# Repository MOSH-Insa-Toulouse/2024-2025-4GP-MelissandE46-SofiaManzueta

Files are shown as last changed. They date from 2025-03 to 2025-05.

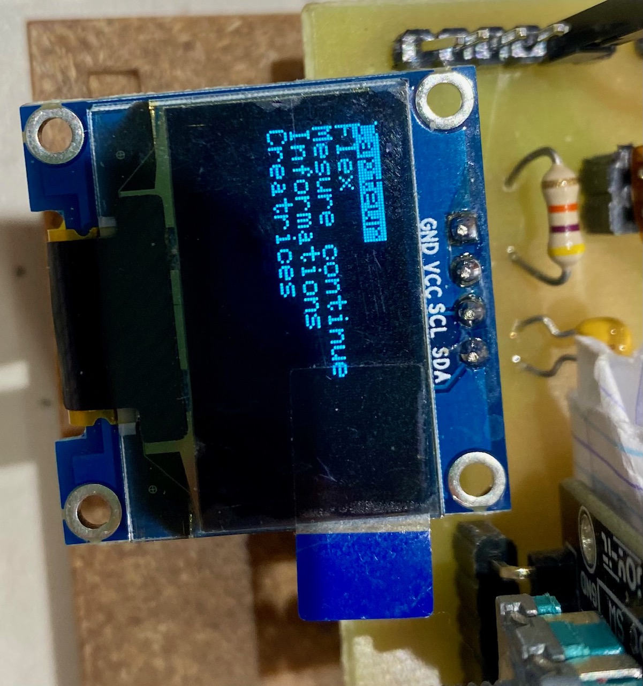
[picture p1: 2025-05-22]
Code Arduino/Menu.jpg

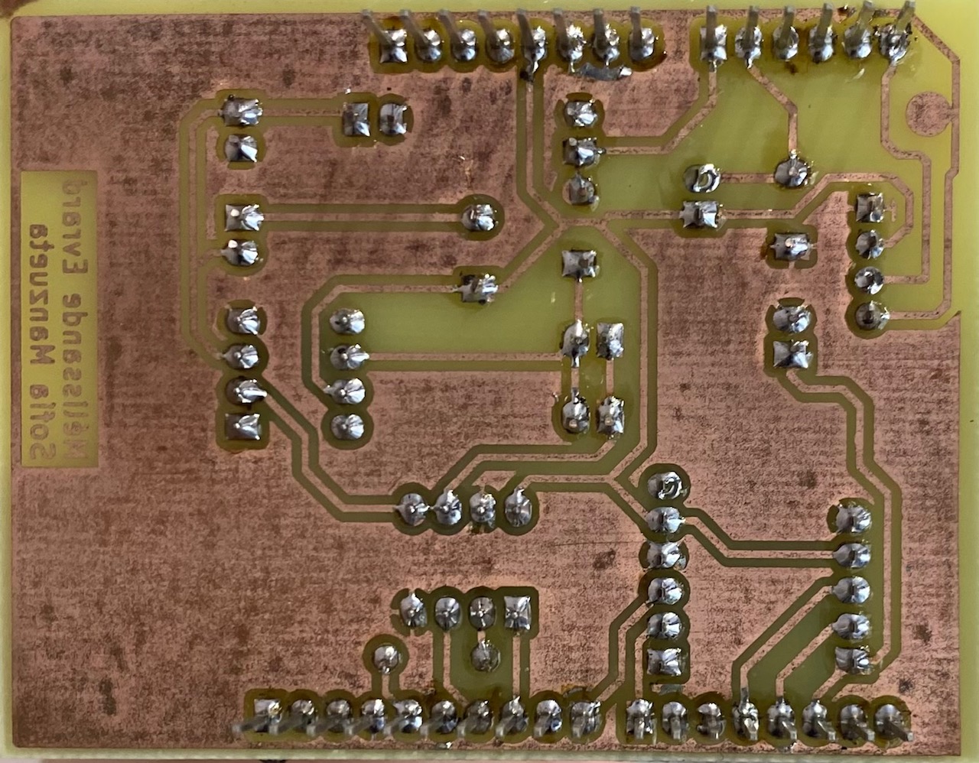
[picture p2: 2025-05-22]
Kidad - Projet capteur/PCB après perçage et soudage.jpg

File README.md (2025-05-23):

# 2024-2025-4GP-MelissandE46-SofiaManzueta

# Projet Capteur

## Sommaire 
*  [Objectifs de ce projet](#objectifs-de-ce-projet)
*  [Déroulé du projet](#diagramme-du-projet)
*  [Simulation du capteur graphite sur LTSpice](#simulation-du-capteur-graphite-sur-ltspice)
*  [Shield PCB sur Kicad](#shield-pcb-sur-kicad)
*  [Code Arduino](#code-arduino)
*  [App Android](#app-android)
*  [La Datasheet](#la-datasheet)

## Objectifs de ce projet

<details>
<summary>  Création d'un capteur de contrainte en graphite  </summary>
   Nous allons utiliser les traces de crayon sur du papier comme une jauge de contrainte pour détecter les déformations en compression et en traction.<br/>
   Les mines de crayon standard sont composées de fines particules de graphite liées entre elles par des liants argileux. Lorsqu'on utilise un crayon, le frottement entre la mine et le papier entraîne le frottement de particules de graphite qui adhèrent aux fibres du papier. Ces traces de crayon peuvent être considérées comme de minces films conducteurs constitués de réseau de particules de graphite percolées sur le papier qui peuvent prendre des formes et des motifs arbitraires. L'expansion et la contraction de ce réseau de particules de graphite, induites par des contraintes mécaniques ou des interactions chimiques, devraient grandement affecter la qualité des contacts interparticulaires et donc le conductivité électrique globale. Il est important de noter que les mines de crayon plus dures contiennent une proportion plus élevée de liants argileux, alors que les mines plus molles contiennent une proportion plus grande de particules de graphite. Ces dernières permettent d'obtenir une résistance de base plus faible qu'avec les mines plus dures. Il a été observé que les variations de résistance moyennes étaient linéairement liées aux amplitudes moyennes de déflexion, avec des écarts d'environ 1%.<br/>
En utilisant la théorie de la percolation, la conductance totale G_{tot} d'un réseau de conducteurs hautement désordonné est :<br/>
   $$G_{tot}=G_0e^{-\xi_c}$$, ici $$\xi_c$$ est la valeur de $$\xi$$ au seuil de percolation qui est le point où un cluster connecté infiniment grand commence à émerger lorsque des paires de nanoparticules voisines choisie au hasard sont connectées par des conducteurs dans un ordre décroissant de valeurs de G<br/>
   If $$-\delta\lambda/2\leq\delta\lambda/2$$,<br/>
   $$\xi_c= \left( {\frac{2f_c\delta\lambda\delta\epsilon}{1-f_v}} \right)^{1/2}+\delta_M-\delta\lambda/2+\epsilon_M-\delta\epsilon/2$$ <br/>
   If $$\delta\lambda/2-\delta\epsilon/2\leq\delta\epsilon/2-\delta\lambda/2$$, <br/>
   $$\xi_c=\lambda_M+\epsilon_M-\left( \frac{1}{2}-\frac{f_c}{1-f_v} \right)\delta\epsilon$$<br/>
   *  $$f_c$$ est la fraction des conducteurs<br/>
   *  $$f_v$$ est la fraction de vide<br/>
   *  $$\lambda_M=L_M\beta$$ et $$E_M=E_{CM}/kT$$ sont les valeurs moyennes des distributions, avec $$L_M$$ l'espace moyen (hors vide) séparant les nanoparticules voisines et $$E_{CM}$$ l'énergie coulombienne de charge moyenne<br/>
   *  $$\delta\lambda$$ et $$\delta\epsilon$$ sont les largeurs des distributions
  
</details>

<details>
<summary>  Réalisation d'un shield PCB pour Arduino UNO  </summary>
   Nous avons créer un shield PCB afin de relier à l'arduino UNO :<br/>  
        *  Un écran OLED  <br/>
        *  Un potentiomètre digital en SPI   <br/>
        *  Un amplificateur transimpédance, lui-même relié au capteur graphite décrit plus haut et au potentiomètre digital  <br/>
        *  Un module Bluetooth  <br/>
        *  Un flex sensor  <br/>
        *  Un encodeur rotatoir auquel on ajoute un déparasite (une capacité entre la clock et le ground)   <br/><br/>

</details>

<details>
<summary>  Création d'un code Arduino  </summary>
Le code crée à l'occasion de ce projet permet de se déplacer dans un menu à l'aide de l'encodeur rotatoire et accéder à différentes fonctions telles que :<br/>
   -La fonction Capteur qui mesure la résistance du capteur graphite, l'affiche sur l'écran OLED et la transmet par bluetooth<br/>
   -La fonction Flex qui mesure la résistance du flex sensor et l'affiche sur l'écran OLED<br/>
   -La fonction Mesure continue qui indique à l'utilisateur la marche à suivre pour réaliser une mesure en continue, que ce soit pour le flex sensor ou le capteur graphite * <br/>
   -La fonction Informations qui renvoie l'utilisateur vers l'application pour Android pour obtenir plus d'informations, l'écran OLED étant très limité<br/>
   -La fonction Creatrices qui indique tout simplement par qui a été réalisé ce projet<br/>

   *Un fil reliant la pin Switch de l'encodeur rotatoire avec le flex sensor a été ajouté. Le but principal est d'agir comme une résistance pull-up pour pouvoir utiliser le bouton switch plus simplement. Cependant, il permet également d'utiliser le flex sensor comme un bouton. En maintenant le flex sensor en compression, on obtient donc des mesures en continue.
   
</details>

<details>
<summary>  Élaboration d'une app Android  </summary>
  Une application a été créée à l'aide de MIT App Inventor (https://appinventor.mit.edu/). Celle-ci permet d'accéder aux mesures réalisées par le capteur graphite, de les afficher dans un graphe et de récupérer ses valeurs dans un fichier. Elle permet également d'obtenir de plus amples informations sur le contexte de ce projet lorsqu'on arrive sur l'écran Informations. Les photos de la partie Designers (ce qui est vu par l'utilisateur) et la partie Blocks (le code derrière l'application) sont disponibles dans le dossier Application Android.
</details>

<details>
<summary>  Rédaction datasheet  </summary>
  Les données de la datasheet proviennent des mesures réalisées avec le code Arduino sur le circuit présenté précédemment. Pour les mines 6B à HB, nous avons mesurer la résistance du capteur graphite pour différentes déformations en tension et en compression. Pour ces déformations, nous avons utilisé des cylindres avec des diamètres de 2cm, 2.5cm, 3cm, 3.5cm, 4cm, 4.5cm et 5cm. Cela nous donne donc des déformations respectivement de 0.1, 0.08, 0.067, 0.057, 0.05, 0.044, 0.04 puisque nous avons mesuré l'épaisseur du capteur e = 0.2cm et que $$\epsilon = \frac{e}{D}$$. On obtient ainsi les courbes caractéristiques suivantes. 
   



Comme on s'y attendait, en cas de compression, la résistance du capteur graphite diminue lorsque la déformation $$\epsilon$$ augmente. A l'inverse, en cas de tension, la résistance du capteur graphite augmente en fonction de la déformation $$\epsilon$$. Pour ces deux cas de figure, nous pouvons observer que la pente de la courbe est dépendante de la mine utilisée. En effet, la variation relative de résistance est plus élevée pour les mines plus dures, comme cela est décrit dans l'article Pencil Drawn Strain Gauges and Chemiresistors on Paper de Cheng-Wei Lin, Zhibo Zhao, Jaemyung Kim et Jiaxing Huang.


Les résultats du capteur graphite peuvent également être comparés à ceux obtenus avec un flex sensor commercial (celui-ci ne peut être utilisé qu'en tension). Tout d'abord, on peut remarquer que les mesures du flex sensor sont bien plus régulières que celles du capteur graphite. De plus, ses variations relatives de résistance sont plus élevées. Il est important de noter que les mesures du capteur graphite, que ce soit en tension ou en compression, sont peu fiables et dépendent en grande partie du reste du matériel utilisé. En effet, d'une mesure à une autre dans des conditions similaires les résultats du capteur peuvent grandement varier. De plus, pour obtenir des résultats cohérents, nous avons dû emprunter les pinces crocodiles d'un autre groupe, sinon peu importe la déformation et la mine utilisées la résistance mesurée était infinie.<br/><br/>
Nous pouvons donc en conclure que le capteur présenté à l'avantage d'être simple, sobre et abordable. Cependant, ses performances sont encore très éloignées de celles d'un flex sensor commercial. De plus, nous avons remarqué que nous devions régulièrement remettre du graphite sur le capteur et le remplacer par un nouveau après l'avoir utilisé en compression et en tension. Cela va donc à l'encontre du principe de la low-tech.

</details>

## Déroulé du projet 

<details>
<summary>  Etapes du projet :  </summary>
  
  - [x] Attribution des inputs de l'arduino aux différents composants
  - [X] Electronique Analogique
  - [x] Schématique et routage KiCad  
  - [x] Impression du circuit
  - [x] Percage
  - [x] Montage du circuit
  - [x] Code Arduino
  - [x] App Android
  - [x] Création du banc de test
  - [x] Création de la datasheet
</details>

## Simulation du capteur graphite sur LTSpice 
* Création d'un capteur de contrainte en graphite
<br/>
Sur le schéma ci-dessus, la partie supérieure à gauche sert à modéliser le capteur graphite.<br/>
C2 filtre le bruit d'alimentation.<br/>
C3 et R5 sont un filtre de sortie.<br/>
C4 et R4 sont un filtre actif.<br/>
R3 correspond au potentiomètre, il permettra donc un changement de calibre.<br/>
C1 et R2 sont un filtre pour le bruit en courant.<br/>
R1 et C1 sont un filtre pour les bruits en tension.<br/>
V3 et C5 simule du bruit.<br/>

## Shield PCB sur Kicad

Des images du schematic, modèle 3D et PCB finale entre autres sont disponibles [ici](https://github.com/MOSH-Insa-Toulouse/2024-2025-4GP-MelissandE46-SofiaManzueta/tree/main/Kidad%20-%20Projet%20capteur)

## Code Arduino

Le code se trouve ici avec une photo du menu déroulant : [Code Arduino](https://github.com/MOSH-Insa-Toulouse/2024-2025-4GP-MelissandE46-SofiaManzueta/tree/main/Code%20Arduino/Final_Code4.0)

## App Android

[Images faces avants et faces arrières de l'application Android](https://github.com/MOSH-Insa-Toulouse/2024-2025-4GP-MelissandE46-SofiaManzueta/tree/main/Application%20Android)

## La Datasheet

[La Datasheet](https://github.com/MOSH-Insa-Toulouse/2024-2025-4GP-MelissandE46-SofiaManzueta/tree/main/Datasheet)

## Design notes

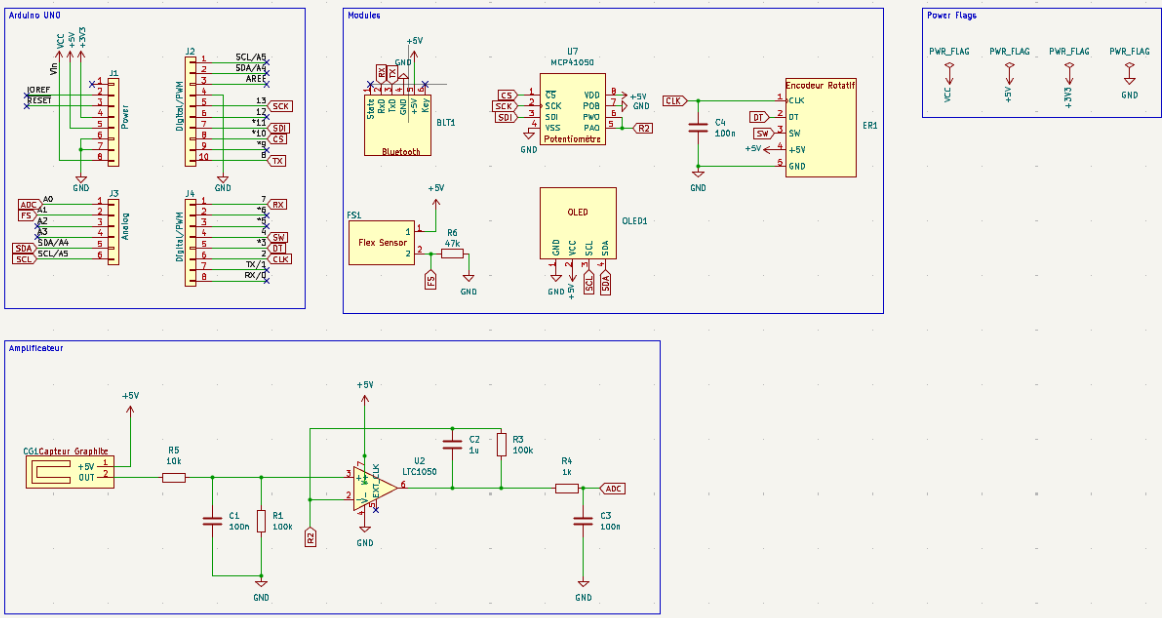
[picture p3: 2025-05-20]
Kidad - Projet capteur/Schematic.png

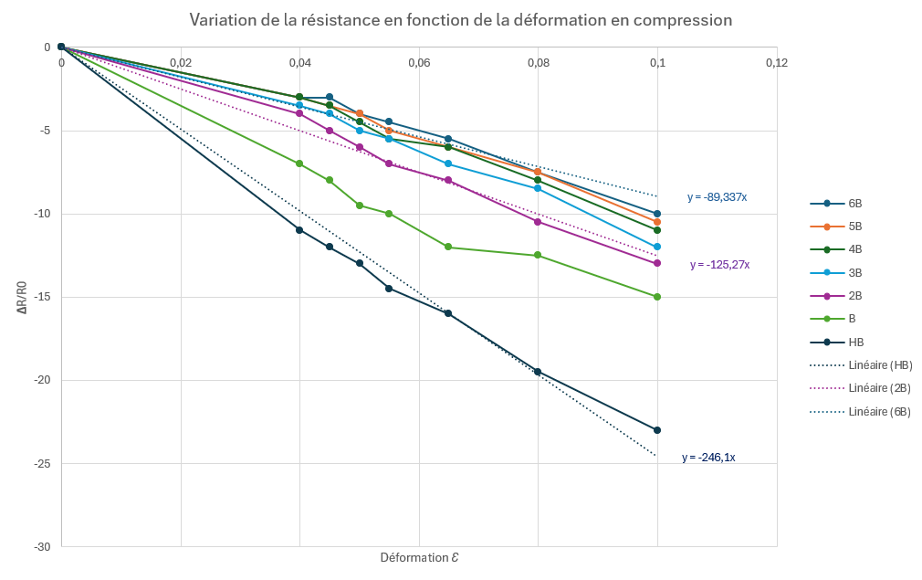
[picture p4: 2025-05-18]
Mesures/Variation résistance capteur graphite compression.PNG

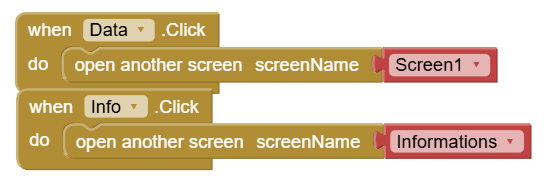
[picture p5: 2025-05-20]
Application Android/Code_Accueil.PNG

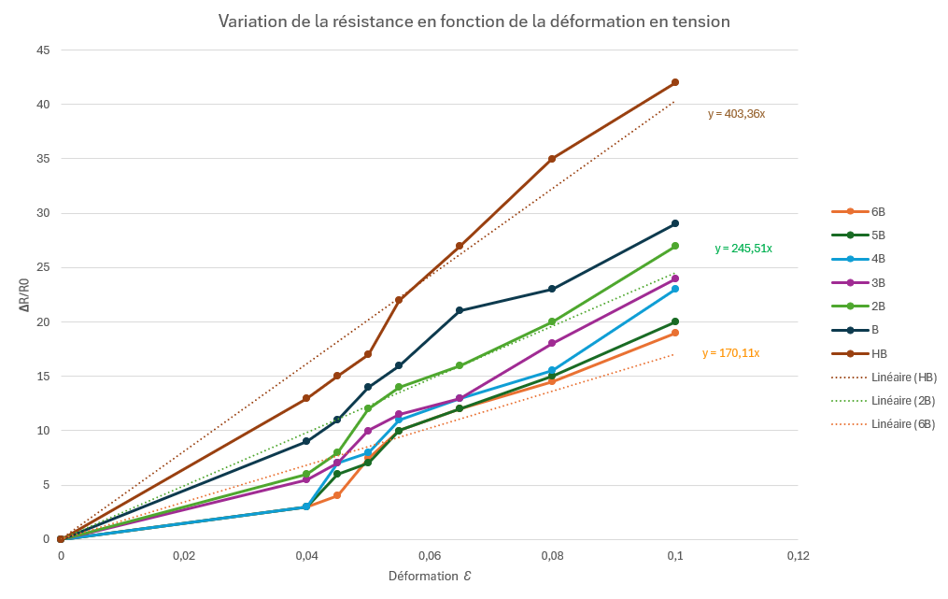
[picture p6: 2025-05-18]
Mesures/Variation résistance capteur graphite tension.PNG

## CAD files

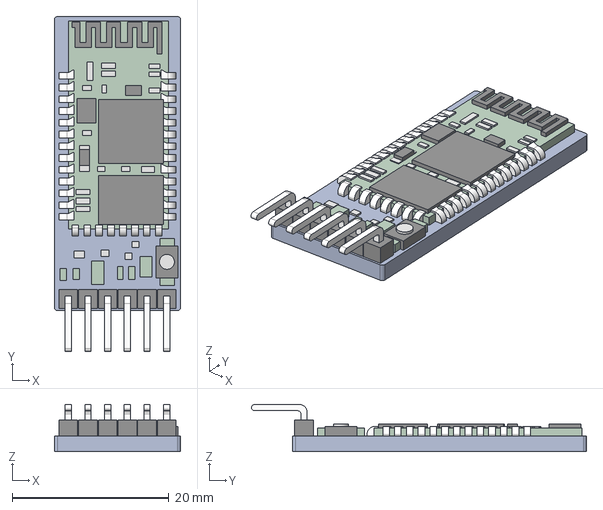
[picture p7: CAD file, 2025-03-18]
Kidad - Projet capteur/Model 3D/HC_05 Blue Tooth Module.stp
16.1 x 42.7 x 6.00 mm

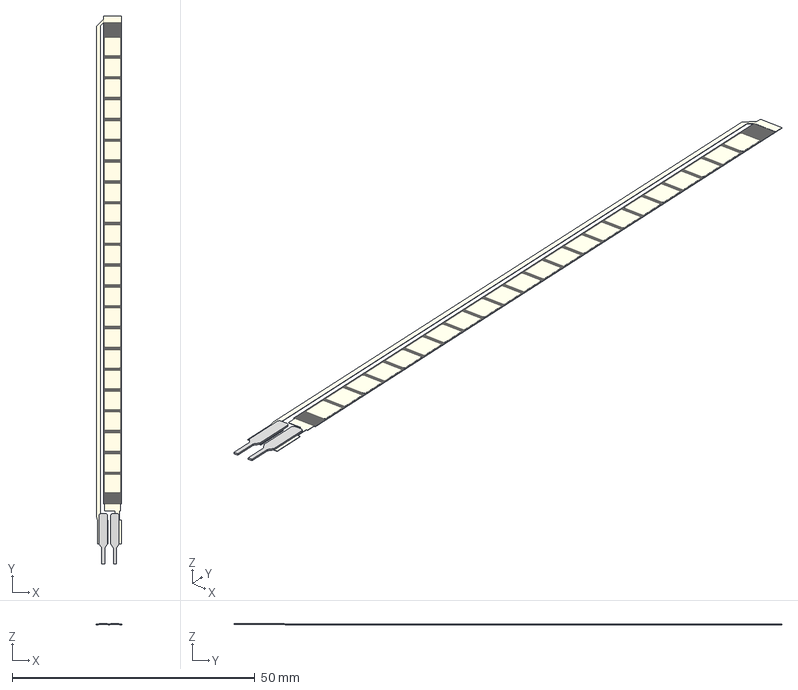
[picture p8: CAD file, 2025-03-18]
Kidad - Projet capteur/Model 3D/flex-sensor.stp
5.17 x 112.8 x 0.292 mm

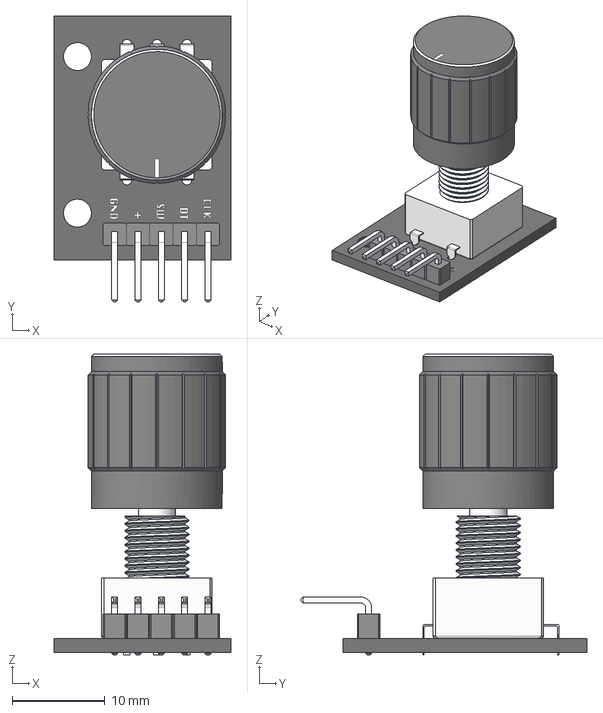
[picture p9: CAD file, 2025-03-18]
Kidad - Projet capteur/Model 3D/Rotary Encoder - KY-040.step
19.0 x 30.8 x 32.4 mm

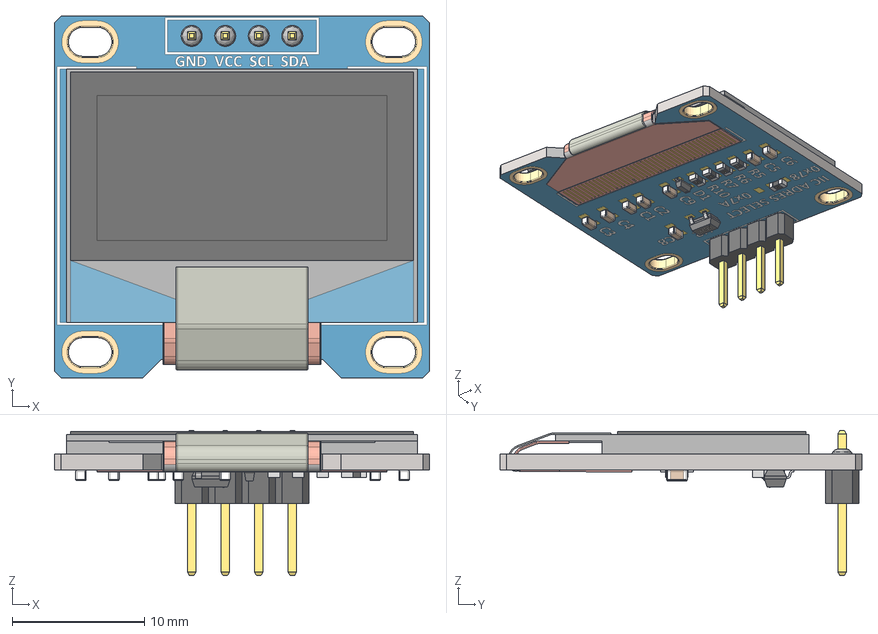
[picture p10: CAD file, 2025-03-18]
Kidad - Projet capteur/Model 3D/Pantalla OLED 0.96'' 128x64.stp
28.4 x 27.4 x 11.0 mm
SOT-23_TOR
RES_CR16_MTK_1 x 4
RES_CR16_MTK
SOD323F_DIO

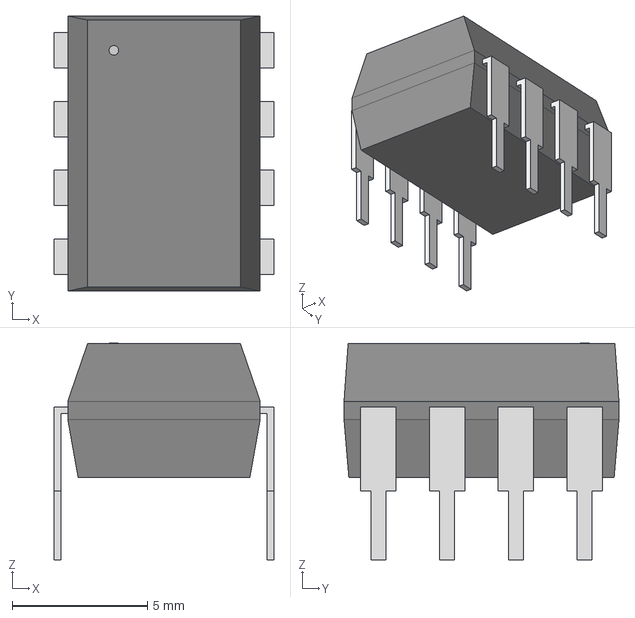
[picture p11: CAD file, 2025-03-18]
Kidad - Projet capteur/Model 3D/PDIP8_300MC_MCH.step
8.13 x 10.2 x 8.00 mm

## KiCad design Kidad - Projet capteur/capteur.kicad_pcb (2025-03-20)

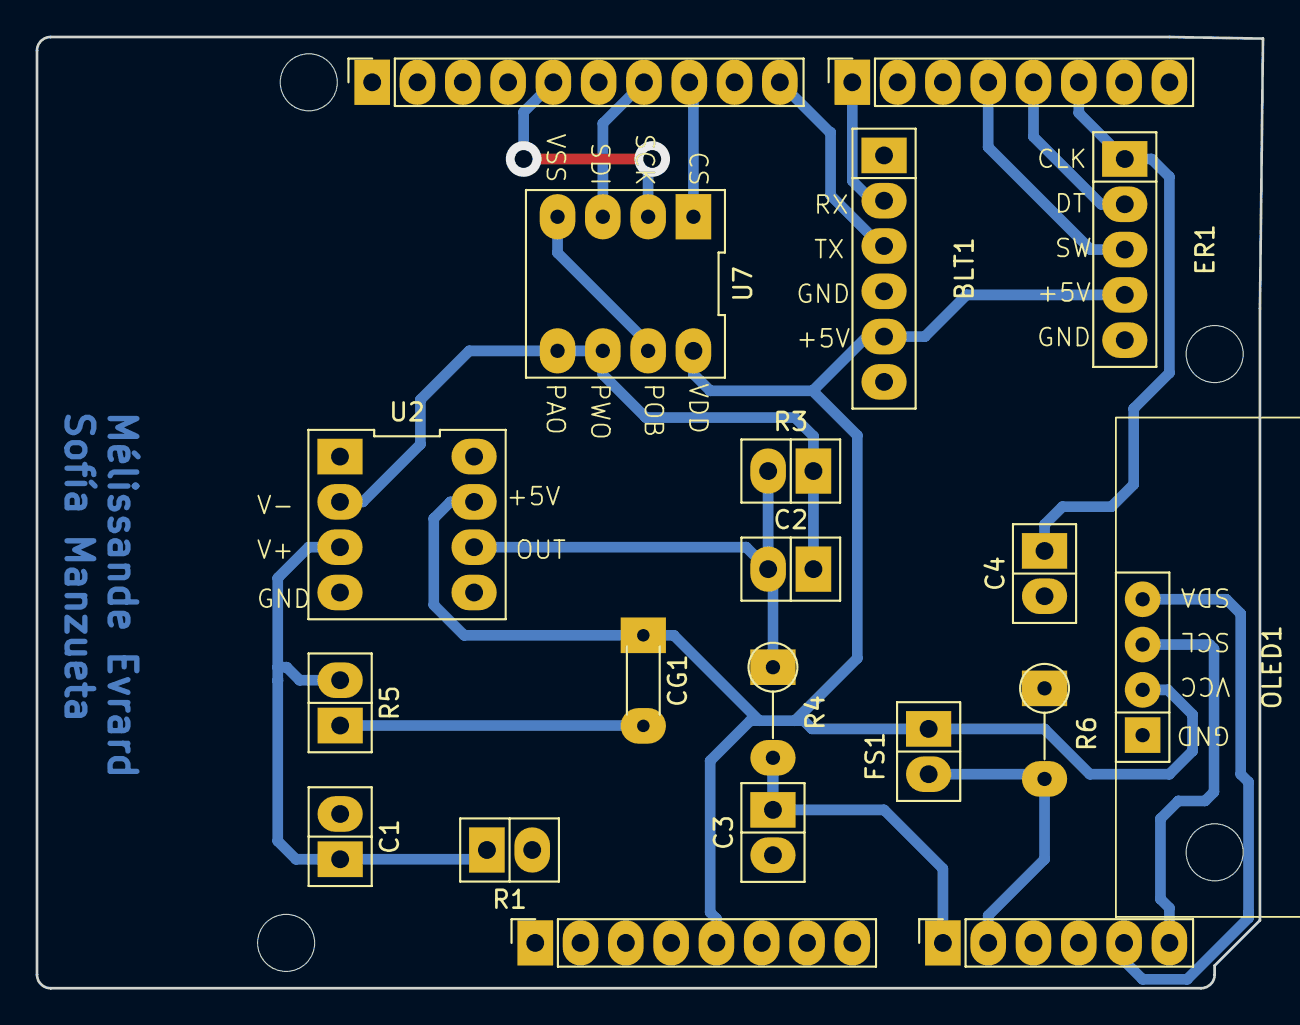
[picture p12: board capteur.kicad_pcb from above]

Board: 2 copper layers, 68.8 x 53.3 mm, 24 parts (0 on the bottom side), 18 nets.

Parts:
BLT1: Bluetooth
C1, C3, C4: 100n; C
C2: 1u; C
CG1: R_Axial_DIN0204_L3.6mm_D1.6mm_P5.08mm_Horizontal
ER1: Encodeur rotatif
FS1: FlexSensor
J1: Power; PinSocket_1x08_P2.54mm_Vertical
J2: Digital/PWM; PinSocket_1x10_P2.54mm_Vertical
J3: Analog; PinSocket_1x06_P2.54mm_Vertical
J4: Digital/PWM; PinSocket_1x08_P2.54mm_Vertical
MH1, MH2, MH3, MH4: MountingHole_3.2mm
OLED1: OLED1306
R1, R3: 100k; R
R4: 1k; R_Axial_DIN0207_L6.3mm_D2.5mm_P5.08mm_Vertical
R5: 10k; R
R6: 47k; R_Axial_DIN0207_L6.3mm_D2.5mm_P5.08mm_Vertical
U2: LTC1050; AOP_LTC1050
U7: MCP41050; Potentiomètre

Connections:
+5V: BLT1.5 (+5V), CG1.1 (+5V), ER1.4 (+5V), FS1.1, J1.5, OLED1.2 (VCC), U2.7 (V+), U7.8 (VDD)
ADC: C3.1, J3.1, R4.2
CLK: C4.1, ER1.1 (CLK), J4.6
CS: J2.8, U7.1 (~CS)
DT: ER1.2 (DT), J4.5
FS: FS1.2, J3.2, R6.2
GND: BLT1.4 (GND), C1.2, C3.2, C4.2, ER1.5 (GND), J1.6, J1.7, J2.4, OLED1.1 (GND), R1.2, R6.1, U2.4 (V-), U7.4 (VSS), U7.7 (POB)
unnamed: C2.2, R3.2, R4.1, U2.6
unnamed: CG1.2 (OUT), R5.1
unnamed: C1.1, R1.1, R5.2, U2.3 (+)
R2: C2.1, R3.1, U2.2 (-), U7.5 (PAO), U7.6 (PWO)
RX: BLT1.2 (RxD), J4.1
SCK: J2.5, U7.2 (SCK)
SCL: J3.6, OLED1.3 (SCL)
SDA: J3.5, OLED1.4 (SDA)
SDI: J2.7, U7.3 (SDI)
SW: ER1.3 (SW), J4.4
TX: BLT1.3 (TxD), J2.10

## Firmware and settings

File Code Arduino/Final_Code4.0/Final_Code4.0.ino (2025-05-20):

//Encodeur~~~~
#define encoder0PinA  2  //CLK 
#define encoder0PinB  3  //DT 
#define Switch 4 // Switch 

int Pos = 1; //correspond au menu surligné de 1 à 5
int Validation = 0; //passe à 1 lorsque le bouton de l'encodeur est appuyé ou lorsqu'on touche au flex sensor
bool SwitchState = HIGH; //récupère l'état du bouton de l'encodeur (ou du flex sensor) par défaut il est HIGH

//Menu~~~~
String menu1 = "Capteur"; //menu pour les mesures classiques de résistance avec le capteur graphite
String menu2 = "Flex"; // menu pour les mesures du flex sensor
String menu3 = "Mesure continue"; //menu pour réaliser la calibration du capteur graphite
String menu4 = "Informations"; //menu nous aiguillant vers l'appli puisqu'il est difficile d'écrire beaucoup d'informations sur l'écran OLED
String menu5 = "Creatrices"; //crédit

unsigned long previousMillis = 0;

//OLED~~~~
#include <Adafruit_SSD1306.h>

#define nombreDePixelsEnLargeur 128         // Taille de l'écran OLED, en pixel, au niveau de sa largeur
#define nombreDePixelsEnHauteur 64          // Taille de l'écran OLED, en pixel, au niveau de sa hauteur
#define brocheResetOLED         -1          // Reset de l'OLED partagé avec l'Arduino (d'où la valeur à -1, et non un numéro de pin)
#define adresseI2CecranOLED     0x3C        // Adresse de "mon" écran OLED sur le bus i2c (généralement égal à 0x3C ou 0x3D)

Adafruit_SSD1306 ecranOLED(nombreDePixelsEnLargeur, nombreDePixelsEnHauteur, &Wire, brocheResetOLED);

//Potentiometre~~~~
#include <SPI.h>

const byte csPin = 10; //MCP42100 chip select pin
const int maxPositions = 256; //wiper can move from 0 to 255 = 256 positions
const long rAB = 50000; // pot resistance between terminals A and B
const byte rWiper = 125; //125 ohms pot wiper resistance
const byte pot0 = 0x11; //pot0 addr // B0001 0001

#define MCP_WRITE 0b00010001; // command byte format xxCCxxPP, CC command, PP pot number (01 if selected)

//Valeurs du circuit~~~~
int R3 = 100000;
int Vcc = 5;
int R1 = 100000;
int R5 = 10000;
double Vadc;
float Resistance;
long R2;

//Module bluetooth~~~~
#include <SoftwareSerial.h>
#define rxPin 7 //Broche 11 en tant que RX, � raccorder sur TX du HC-05
#define txPin 8 //Broche 10 en tant que RX, � raccorder sur TX du HC-05
#define baudrate 9600
SoftwareSerial mySerial(rxPin ,txPin); //D�finition du software serial

//Flex sensor~~~~
const int flexPin = A1;      // Pin connected to voltage divider output

const float VCC = 5;
const float R_DIV = 47000.0;  // resistor used to create a voltage divider
const float flatResistance = 25000.0; // resistance when flat
const float bendResistance = 100000.0;  // resistance at 90 deg
int ADCflex;
float Vflex;
float Rflex;
float angle;


void setPot(int addr, int pospot){
  SPI.beginTransaction(SPISettings(14000000, MSBFIRST, SPI_MODE0));
  pospot = constrain (pospot, 0, 255); //limit wiper setting to range of 0 to 255
  digitalWrite(csPin, LOW); //select chip
  SPI.transfer(addr); // configure target pot with wiper position
  SPI.transfer(pospot);
  digitalWrite(csPin, HIGH); //de-select chip
  //print pot resistance between wiper and B terminal
  R2 = ((rAB * pospot) / maxPositions) + rWiper;
  Serial.print("Wiper pos : ");
  Serial.print(pospot);
  Serial.print("  R2 : ");
  Serial.print(R2);
  Serial.println("ohms");
}

void setup() {
  Serial.begin(9600);
  // Initialisation potentiometre
  digitalWrite(csPin, HIGH); // chip select default to de-selected
  pinMode(csPin, OUTPUT); // configure chip select as output
  SPI.begin();
  // Initialisation Bluetooth
  pinMode(rxPin,INPUT);
  pinMode(txPin,OUTPUT);
  mySerial.begin(9600);
  //Initialisation flex sensor
  pinMode(flexPin, INPUT);
  // Initialisation encoder
  pinMode(encoder0PinA, INPUT);        
  pinMode(encoder0PinB, INPUT);  
  pinMode(Switch, INPUT);   

  attachInterrupt(0, doEncoder, RISING); 
  // Initialisation ecran OLED
  if(!ecranOLED.begin(SSD1306_SWITCHCAPVCC, adresseI2CecranOLED)){
    while(1);
  }  
}

void Flex_Sensor(){
  // Read the ADC and calculate voltage and resistance from it
  ADCflex = analogRead(flexPin);
  Vflex = ADCflex * VCC / 1024.0;
  Rflex = R_DIV * (VCC /Vflex - 1.0);
  Serial.print("Resistance : ");
  Serial.print(Rflex);
  Serial.println("ohms");
  ecranOLED.clearDisplay();
  ecranOLED.setTextSize(1);
  ecranOLED.setCursor(0, 0);
  ecranOLED.setTextColor(SSD1306_WHITE, SSD1306_BLACK);
  ecranOLED.print(F("Resistance flex"));
  ecranOLED.setCursor(0,15);
  ecranOLED.print(Rflex);
  ecranOLED.setCursor(40,15);
  ecranOLED.print(F("ohms"));
  ecranOLED.display();
}

void Calcul(){
  //Calcule la résistance au niveau du capteur graphite
  Vadc = analogRead(A0) * 5 /1023;
  Serial.print("Vadc = ");
  Serial.print(Vadc * 1024 / 5);
  Serial.print("Volts");
  Resistance = (1 + R3 / R2) * R1 * Vcc / Vadc - R1 -R5;
  double ResistanceM;
  ResistanceM = Resistance/1000000; //pour passer en Mega ohms
  mySerial.print(ResistanceM);
  ecranOLED.clearDisplay();
  ecranOLED.setTextSize(1);
  ecranOLED.setCursor(0, 0);
  ecranOLED.setTextColor(SSD1306_WHITE, SSD1306_BLACK);
  ecranOLED.print(F("Resistance capteur"));
  ecranOLED.setCursor(0,15);
  ecranOLED.print(Resistance);
  ecranOLED.setCursor(40,15);
  ecranOLED.print(F("ohms"));
  ecranOLED.display();
}
void loop() {
  //Affichage des différents menus
  Menu ();
}

void doEncoder() {
  //Permet de déplacer le "curseur" sur le menu en fonction de l'encodeur rotatoire
  if (Pos < 5 && digitalRead(encoder0PinA)==HIGH && digitalRead(encoder0PinB)==HIGH) {
    Pos++;
  } else if (Pos > 1 && digitalRead(encoder0PinA)==HIGH && digitalRead(encoder0PinB)==LOW) {
    Pos--;
  }
  else if (Pos == 5 && digitalRead(encoder0PinA)==HIGH && digitalRead(encoder0PinB)==HIGH){
    Pos = 1;
  }
  else if (Pos == 1 && digitalRead(encoder0PinA)==HIGH && digitalRead(encoder0PinB)==LOW){
    Pos = 5;
  } 
  
}

void Menu(){
  unsigned long currentMillis = millis ();
  
  SwitchState = digitalRead(Switch); //récupère la valeur du bouton de l'encodeur
  if (SwitchState == LOW){
    Validation = 1;
    SwitchState = HIGH;
  }

  
  if (currentMillis - previousMillis >= (500)){
    previousMillis = currentMillis;
    ecranOLED.clearDisplay();
    ecranOLED.setTextSize(1);
    ecranOLED.setCursor(0, 0);
    ecranOLED.setTextColor(SSD1306_WHITE, SSD1306_BLACK); //on réinitialise l'affichage de l'écran OLED
    
    
    if (Pos==1){
      ecranOLED.setTextColor(SSD1306_BLACK, SSD1306_WHITE);
      ecranOLED.println(menu1);
      ecranOLED.setTextColor(SSD1306_WHITE, SSD1306_BLACK);
      ecranOLED.println(menu2);
      ecranOLED.println(menu3);
      ecranOLED.println(menu4);
      ecranOLED.println(menu5);
      ecranOLED.display();
      if (Validation == 1){
        setPot(pot0, 1); //potentiometre à un niveau bas car le capteur graphite ne fonctionne pas bien 
        Calcul();
        delay(1000);
        Validation = 0;
      }
      
    }
    else if (Pos==2){
      ecranOLED.println(menu1);
      ecranOLED.setTextColor(SSD1306_BLACK, SSD1306_WHITE);
      ecranOLED.println(menu2);
      ecranOLED.setTextColor(SSD1306_WHITE, SSD1306_BLACK);
      ecranOLED.println(menu3);
      ecranOLED.println(menu4);
      ecranOLED.println(menu5);
      ecranOLED.display();
      if (Validation == 1){
        Flex_Sensor();
        delay(1000);
        Validation = 0;
      }
    }
    else if (Pos==3){
      ecranOLED.println(menu1);
      ecranOLED.println(menu2);
      ecranOLED.setTextColor(SSD1306_BLACK, SSD1306_WHITE);
      ecranOLED.println(menu3);
      ecranOLED.setTextColor(SSD1306_WHITE, SSD1306_BLACK);
      ecranOLED.println(menu4);
      ecranOLED.println(menu5);
      ecranOLED.display();
      if (Validation == 1){
        ecranOLED.clearDisplay();
        ecranOLED.setTextSize(1);
        ecranOLED.setCursor(0, 0);
        ecranOLED.setTextColor(SSD1306_WHITE, SSD1306_BLACK);      
        ecranOLED.println(F("Selectionner le menu Capteur"));     
        ecranOLED.setCursor(0, 20);
        ecranOLED.println(F("Appuyez sur le flex sensor"));
        ecranOLED.setCursor(0, 40);  
        ecranOLED.println(F("Le temps de la mesure"));   
        ecranOLED.display();
        delay(3000);
        Validation = 0;
      }
    }
    else if (Pos == 4){
      ecranOLED.println(menu1);
      ecranOLED.println(menu2);
      ecranOLED.println(menu3);
      ecranOLED.setTextColor(SSD1306_BLACK, SSD1306_WHITE);
      ecranOLED.println(menu4);
      ecranOLED.setTextColor(SSD1306_WHITE, SSD1306_BLACK);
      ecranOLED.println(menu5);
      ecranOLED.display();
      if (Validation == 1){
        ecranOLED.clearDisplay();
        ecranOLED.setTextSize(1);
        ecranOLED.setCursor(0, 0);
        ecranOLED.setTextColor(SSD1306_WHITE, SSD1306_BLACK);      
        ecranOLED.println(F("Une application"));
        ecranOLED.setCursor(0, 20);
        ecranOLED.print(F("bluetooth"));
        ecranOLED.setCursor(0,40);
        ecranOLED.print(F("est disponible")); //la fonction F() permet d'utiliser moins de RAM    
        ecranOLED.display();
        delay(2000);
        Validation = 0;
      }
    }
    else if (Pos == 5){
      ecranOLED.println(menu1);
      ecranOLED.println(menu2);
      ecranOLED.println(menu3);
      ecranOLED.println(menu4);
      ecranOLED.setTextColor(SSD1306_BLACK, SSD1306_WHITE);
      ecranOLED.println(menu5);
      ecranOLED.setTextColor(SSD1306_WHITE, SSD1306_BLACK);
      ecranOLED.display();
      if (Validation == 1){
        ecranOLED.clearDisplay();
        ecranOLED.setTextSize(1);
        ecranOLED.setCursor(0, 0);
        ecranOLED.setTextColor(SSD1306_WHITE, SSD1306_BLACK);      
        ecranOLED.println(F("Projet realise par"));
        ecranOLED.setCursor(0, 20);
        ecranOLED.print(F("Sofia et Melissande")); //la fonction F() permet d'utiliser moins de RAM      
        ecranOLED.display();
        delay(2000);
        Validation = 0;
      }        
    }
    
  }

}

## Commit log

2025-02-21 Modif de ligne 5 du fichier README
2025-05-20 Add files via upload
    Add of pictures from Kicad
2025-05-20 Add files via upload
    Add of Arduino code
